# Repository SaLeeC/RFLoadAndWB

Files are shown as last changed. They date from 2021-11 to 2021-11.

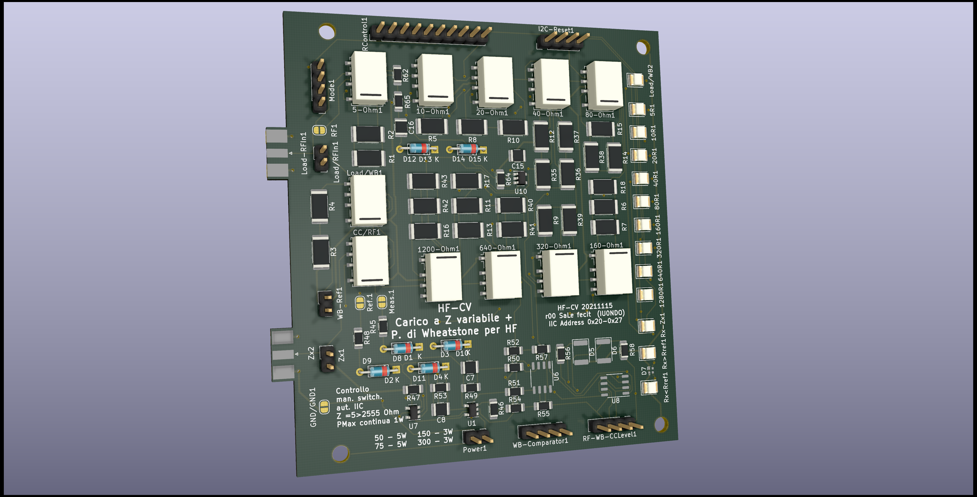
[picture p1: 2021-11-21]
HF_CaricoVariabile/Doc/HF_CaricoVariabile_r00-Front.png

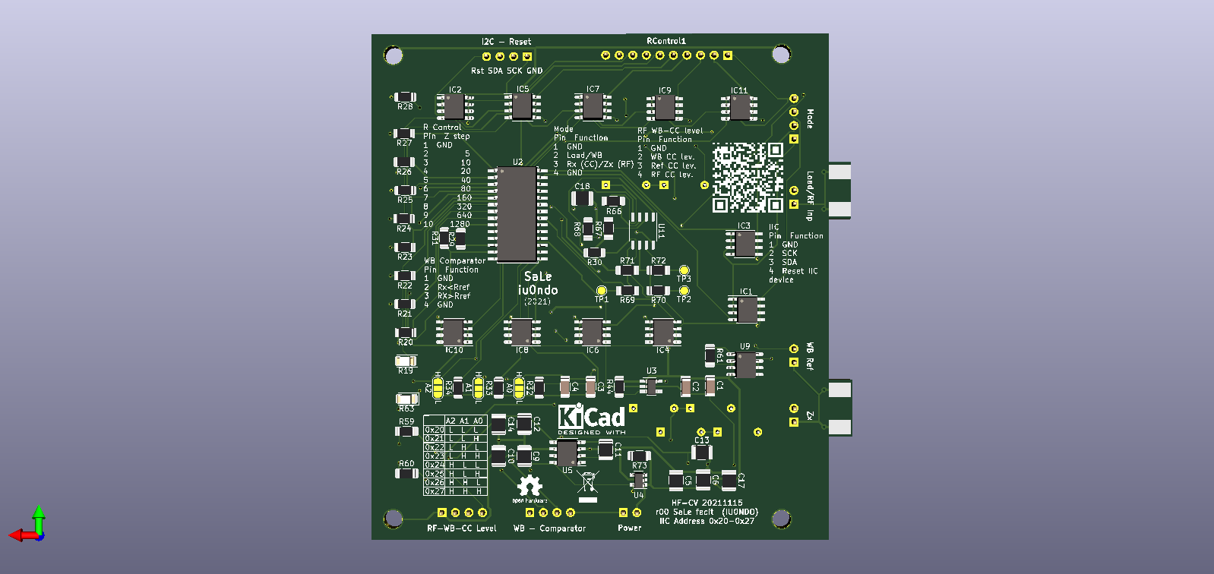
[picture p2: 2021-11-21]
HF_CaricoVariabile/Doc/HF_CaricoVariabile_r00-rear.png

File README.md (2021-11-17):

# RFLoadAndWB
A board to have a low power Variable Z Load and a RF Wheatstone Bridge

The intention is to make a small card (under 10 X 10 cm) that provides a dummy load (low power) with variable impedance between 5 and 2555 Ohm programmable in 5 Ohm steps and, at the same time, a Weathston Bridge which works in direct current and in RF to measure the unknown Z always in the range between 5 and 2555 Ohm.

The project is based on the following finished functional blocks:

a) Variable Z dummy load

b) Reference divider for the Weathston Bridge

c) Constant Current Generator

d) RF-DC converter for the measurement of the incoming Radio Frequency level

e) RF-DC converter for measuring the level of the reference Radio Frequency for the Weathston Bridge

f) RF-DC converter for measuring the level across the Unknown Impedance

g) Comparator for the comparison between the reference and the level at the ends of the Unknown Impedance

h) LED display for the representation of the board status (including the result of the comparison)

i) IIC interface for setting the operating parameters

All modules are finished units so they can be assembled, tested and used separately from each other.

For its operation, the board does not require a microcontroller, PC, software or other devilry, it only requires a series of switches or jumpers with which we can manually set all the operating parameters.

For the measurements a tester or a multimeter is sufficient because all the measured values are converted into Direct Current.

For direct current resistance measurements, the unknown resistor is powered by a 1 mA constant current pump allowing to read its value in Ohm directly in mV.

It is also possible to connect the card to a microcontroller through the interface module in IIC (I2C).

As for the measured values, these are converted into Direct Current and can assume values between 0 and 3.3V allowing easy interfacing with the Analog-Digital converters which are normally equipped with microcontrollers.

The comparator output is digital information and assumes the values of 0 or 3.3V

All the elements that make up the Dummy Load are 1W SMD resistors for which 1W is assumed as the maximum applicable power, in fact, since only the value of 10 Ohm is obtained with a single resistor, if really necessary, it will be possible to apply higher powers in function of the set value. This operation can irreversibly damage the load if during use combinations are chosen that are not able to withstand the applied power. In any case it is recommended not to apply more than 2W.

Inside the board hare present a free Op Amp with minimum circuit usable with Inp+ Inp- and Out for integration and experimental use

All schematics and PCB design are provided in KiCad format

The software is developed with Visual Studio Code through the PlatformIo App and is compatible with the "Arduino" environment

Mechanical drawings are produced with FreeCad.

# RFLoadAndWB
Una scheda che faccia da Carico Fittizio ad Impedenza Variabile e da Ponte di Weathston in RF

l'intenzione è quella di realizzare una piccola scheda (sotto i 10 X 10 cm) che fornisca un carico fittizio (bassa potenza) con impedenza variabile tra 5 e 2555 Ohm programmabile in step di 5 Ohm e, allo stesso tempo, un Weathston Bridge che funzioni in in corrente continua e in RF per misurare lo Z sconosciuto sempre nel range tra 5 e 2555 Ohm.

Il progetto è basato sui seguenti blocchi funzionali finiti:

a) Carico fittizio a Z variabile

b) Partitore di riferimento per il Ponte di Weathston

c) Generatore di Corrente Costante

d) Convertitore RF-DC per la misura del livello della Radio Frequenza in ingresso

e) Convertitore RF-DC per la misura del livello della Radio Frequenza di riferimento per il Ponte di Weathston

f) Convertitore RF-DC per la misura del livello ai capi della Impedenza Incognita

g) Comparatore per il confronto fra il riferimento e il livello ai capi della Impedenza Incognita

h) Display a LED per la rappresentazione dello stato della scheda (compreso il risultato della comparazione)

i) Interfaccia IIC per l'impostazione dei parametri di funzionamento

Tutti i moduli sono unità finite per cui possono essere assemblati, testati e usati separatamente uno dall'altro. 

Per il suo funzionamento la scheda non necessita di microcontrollore, PC, software o altre diavolerie, richiede solo una serie di interruttori o ponticelli con i quali possiamo manualmente impostare tutti i parametri di funzionamento.

Per le misure è sufficiente un tester o un multimetro perchè tutti i valori misurati sono convertiti in Corrente Continua.

Per le misure di resistenza in Corrente Continua la resistenza incognita è alimentata con una pompa di corrente costante da 1 mA permettendo di leggerne il valore in Ohm direttamente in mV.

E' altresì possibile collegare la scheda ad un microcontrollore tramite il modulo di interfacciamento in IIC (I2C).

Per quanto riguarda i valori misurati, questi sono convertiti in Corrente Continua e possono assumere valori compresi fra 0 e 3.3V permettendo un agevole interfacciamento con i convertitori Analogico Digitali di cui normalmente sono dotati i microcontrollori.

L'uscita del comparatore è una informazione digitale ed assume i valori di 0 o 3.3V

Tutti gli elementi che compongono il Carico Fittizio sono resistenze SMD da 1W per cui si assume 1W come potenza massima applicabile, in effetti, siccome solo il valore di 10 Ohm è ottenuto con una sola resistenza, se realmente necessario,sarà possibile applicare potenze maggiori  in funzione del valore impostato. Questa operazione può danneggiare irreversibilmente il carico se durante l'uso si scelgono combinazioni che non siano in grado di sopportare la potenza applicata. In ogni caso si consiglia di non applicare più di 2W.

All'interno della scheda è presente un Op Amp circuitato con i componenti minimi e utilizzabile tramite i pin Inp+ Inp- e Out, da usare per integrazioni o esperimenti.

Tutti gli schemi e il progetto del PCB sono forniti in formato KiCad

Il software è sviluppato con Visual Studio Code tramite l'App PlatformIo ed è compatibile con l'ambiente "Arduino"

I disegni meccanici sono prodotti con FreeCad.

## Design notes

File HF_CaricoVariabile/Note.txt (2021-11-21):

#Comparatrore-Uscita digitale
Dopo aver completato la prima messa a punto del Weatston Bridge e verificato il corretto funzionamento dei singoli blocchi, verificare la corretta sovrapponibilità dell'uscita digitale del comparatore con due bit dell'espander così da poter leggere il comparatore direttamente in I2C.
Questa modifica va fatta aggiungendo due ponticelli cablati

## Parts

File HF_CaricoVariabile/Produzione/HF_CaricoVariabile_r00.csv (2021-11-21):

Reference | Value | Footprint | Datasheet | Arrow Part Number | Arrow Price/Stock | Description | Height | Manufacturer_Name | Manufacturer_Part_Number | Mouser Part Number | Mouser Price/Stock
I2C-Reset1 | Conn_01x04_Female | Connector_PinHeader_2.54mm:PinHeader_1x04_P2.54mm_Vertical | ~
Power1 | Conn_01x02_Female | Connector_PinHeader_2.54mm:PinHeader_1x02_P2.54mm_Vertical | ~
RF-WB-CCLevel1 | Conn_01x04_Female | Connector_PinHeader_2.54mm:PinHeader_1x04_P2.54mm_Vertical | ~
WB-Comparator1 | Conn_01x04_Female | Connector_PinHeader_2.54mm:PinHeader_1x04_P2.54mm_Vertical | ~
Mode1 | Conn_01x04_Female | Connector_PinHeader_2.54mm:PinHeader_1x04_P2.54mm_Vertical | ~
RControl1 | Conn_01x10_Female | Connector_PinHeader_2.54mm:PinHeader_1x10_P2.54mm_Vertical | ~
GND/GND1 | GND/GND | Jumper:SolderJumper-2_P1.3mm_Open_RoundedPad1.0x1.5mm | ~
D16 | SD12 | Diode_SMD:D_1812_4532Metric | https://assets.nexperia.com/documents/data-sheet/1N4148_1N4448.pdf
Rx-Zx2 | LED | LED_SMD:LED_1210_3225Metric | ~
R74 | R | LED_SMD:LED_1206_3216Metric | ~
R2 | 10 | Resistor_SMD:R_2512_6332Metric | ~
5-Ohm1 | 5 Ohm | Relay_SMD:Relay_DPDT_Omron_G6K-2F-Y | http://omronfs.omron.com/en_US/ecb/products/pdf/en-g6k.pdf
Load-RFIn1 | Load/RFin | Connector_Coaxial:SMA_Molex_73251-2120_EdgeMount_Horizontal | ~
10-Ohm1 | 10 Ohm | Relay_SMD:Relay_DPDT_Omron_G6K-2F-Y | http://omronfs.omron.com/en_US/ecb/products/pdf/en-g6k.pdf
R1 | 10 | Resistor_SMD:R_2512_6332Metric | ~
20-Ohm1 | 20 Ohm | Relay_SMD:Relay_DPDT_Omron_G6K-2F-Y | http://omronfs.omron.com/en_US/ecb/products/pdf/en-g6k.pdf
40-Ohm1 | 40 Ohm | Relay_SMD:Relay_DPDT_Omron_G6K-2F-Y | http://omronfs.omron.com/en_US/ecb/products/pdf/en-g6k.pdf
R5 | 10 | Resistor_SMD:R_2512_6332Metric | ~
80-Ohm1 | 80 Ohm | Relay_SMD:Relay_DPDT_Omron_G6K-2F-Y | http://omronfs.omron.com/en_US/ecb/products/pdf/en-g6k.pdf
160-Ohm1 | 160 Ohm | Relay_SMD:Relay_DPDT_Omron_G6K-2F-Y | http://omronfs.omron.com/en_US/ecb/products/pdf/en-g6k.pdf
320-Ohm1 | 320 Ohm | Relay_SMD:Relay_DPDT_Omron_G6K-2F-Y | http://omronfs.omron.com/en_US/ecb/products/pdf/en-g6k.pdf
640-Ohm1 | 640 Ohm | Relay_SMD:Relay_DPDT_Omron_G6K-2F-Y | http://omronfs.omron.com/en_US/ecb/products/pdf/en-g6k.pdf
1200-Ohm1 | 1200 Ohm | Relay_SMD:Relay_DPDT_Omron_G6K-2F-Y | http://omronfs.omron.com/en_US/ecb/products/pdf/en-g6k.pdf
R15 | 120 | Resistor_SMD:R_2512_6332Metric | ~
R14 | 120 | Resistor_SMD:R_2512_6332Metric | ~
R9 | 100 | Resistor_SMD:R_2512_6332Metric | ~
R6 | 330 | Resistor_SMD:R_2512_6332Metric | ~
R11 | 330 | Resistor_SMD:R_2512_6332Metric | ~
R13 | 100 | Resistor_SMD:R_2512_6332Metric | ~
R16 | 4700 | Resistor_SMD:R_2512_6332Metric | ~
R17 | 1000 | Resistor_SMD:R_2512_6332Metric | ~
Load/WB1 | 5 Ohm | Relay_SMD:Relay_DPDT_Omron_G6K-2F-Y | http://omronfs.omron.com/en_US/ecb/products/pdf/en-g6k.pdf
Zx2 | Zx | Connector_Coaxial:SMA_Molex_73251-2120_EdgeMount_Horizontal | ~
R4 | 1000 | Resistor_SMD:R_2512_6332Metric | ~
R3 | 1000 | Resistor_SMD:R_2512_6332Metric | ~
Load/RFIn1 | Load/RFIn | Connector_PinHeader_2.54mm:PinHeader_1x02_P2.54mm_Vertical | ~
WB-Ref1 | RFRef | Connector_PinHeader_2.54mm:PinHeader_1x02_P2.54mm_Vertical | ~
Zx1 | Zx | Connector_PinHeader_2.54mm:PinHeader_1x02_P2.54mm_Vertical | ~
R8 | 10 | Resistor_SMD:R_2512_6332Metric | ~
R10 | 10 | Resistor_SMD:R_2512_6332Metric | ~
R12 | 10 | Resistor_SMD:R_2512_6332Metric | ~
R37 | 10 | Resistor_SMD:R_2512_6332Metric | ~
R35 | 10 | Resistor_SMD:R_2512_6332Metric | ~
R36 | 10 | Resistor_SMD:R_2512_6332Metric | ~
R38 | 120 | Resistor_SMD:R_2512_6332Metric | ~
R7 | 330 | Resistor_SMD:R_2512_6332Metric | ~
R18 | 4700 | Resistor_SMD:R_2512_6332Metric | ~
R39 | 220 | Resistor_SMD:R_2512_6332Metric | ~
R40 | 220 | Resistor_SMD:R_2512_6332Metric | ~
R41 | 4700 | Resistor_SMD:R_2512_6332Metric | ~
R42 | 330 | Resistor_SMD:R_2512_6332Metric | ~
R43 | 4700 | Resistor_SMD:R_2512_6332Metric | ~
U9 | LM334M | Package_SO:SOIC-8_3.9x4.9mm_P1.27mm | http://www.ti.com/lit/ds/symlink/lm134.pdf
R61 | 68 | Resistor_SMD:R_1206_3216Metric_Pad1.30x1.75mm_HandSolder | ~
CC/RF1 | CC-RF | Relay_SMD:Relay_DPDT_Omron_G6K-2F-Y | http://omronfs.omron.com/en_US/ecb/products/pdf/en-g6k.pdf
U7 | OPA356 | Package_TO_SOT_SMD:SOT-23-5 | http://www.ti.com/lit/ds/symlink/opa356.pdf
R53 | 220K | Resistor_SMD:R_1206_3216Metric_Pad1.30x1.75mm_HandSolder | ~
R48 | 100K | Resistor_SMD:R_1206_3216Metric_Pad1.30x1.75mm_HandSolder | ~
U5 | ICL7660 | Package_SO:SOIC-8_3.9x4.9mm_P1.27mm | http://datasheets.maximintegrated.com/en/ds/ICL7660-MAX1044.pdf
U4 | TLV70033_SOT23-5 | Package_TO_SOT_SMD:SOT-23-5 | http://www.ti.com/lit/ds/symlink/tlv700.pdf
R57 | 10k | Resistor_SMD:R_1206_3216Metric_Pad1.30x1.75mm_HandSolder | ~
D4 | 1N4148 | Diode_THT:D_DO-35_SOD27_P7.62mm_Horizontal | https://assets.nexperia.com/documents/data-sheet/1N4148_1N4448.pdf
D2 | 1N4148 | Diode_THT:D_DO-35_SOD27_P7.62mm_Horizontal | https://assets.nexperia.com/documents/data-sheet/1N4148_1N4448.pdf
R55 | 10K | Resistor_SMD:R_1206_3216Metric_Pad1.30x1.75mm_HandSolder | ~
C8 | 100n | Resistor_SMD:R_1210_3225Metric | ~
R47 | 47K | Resistor_SMD:R_1206_3216Metric_Pad1.30x1.75mm_HandSolder | ~
U1 | OPA356 | Package_TO_SOT_SMD:SOT-23-5 | http://www.ti.com/lit/ds/symlink/opa356.pdf
R49 | 220K | Resistor_SMD:R_1206_3216Metric_Pad1.30x1.75mm_HandSolder | ~
R45 | 100K | Resistor_SMD:R_1206_3216Metric_Pad1.30x1.75mm_HandSolder | ~
D3 | 1N4148 | Diode_THT:D_DO-35_SOD27_P7.62mm_Horizontal | https://assets.nexperia.com/documents/data-sheet/1N4148_1N4448.pdf
D1 | 1N4148 | Diode_THT:D_DO-35_SOD27_P7.62mm_Horizontal | https://assets.nexperia.com/documents/data-sheet/1N4148_1N4448.pdf
C7 | 100n | Resistor_SMD:R_1210_3225Metric | ~
R46 | 47K | Resistor_SMD:R_1206_3216Metric_Pad1.30x1.75mm_HandSolder | ~
U6 | TL072 | Package_SO:SOP-8_3.9x4.9mm_P1.27mm | http://www.ti.com/lit/ds/symlink/tl071.pdf
R54 | 10K | Resistor_SMD:R_1206_3216Metric_Pad1.30x1.75mm_HandSolder | ~
R52 | 10K | Resistor_SMD:R_1206_3216Metric_Pad1.30x1.75mm_HandSolder | ~
R50 | 100K | Resistor_SMD:R_1206_3216Metric_Pad1.30x1.75mm_HandSolder | ~
R51 | 100K | Resistor_SMD:R_1206_3216Metric_Pad1.30x1.75mm_HandSolder | ~
Ref.1 | Jumper_2_Open | Jumper:SolderJumper-2_P1.3mm_Open_RoundedPad1.0x1.5mm | ~
Meas.1 | Jumper_2_Open | Jumper:SolderJumper-2_P1.3mm_Open_RoundedPad1.0x1.5mm | ~
C6 | 100n | Resistor_SMD:R_1210_3225Metric | ~
C5 | 100u | Resistor_SMD:R_1210_3225Metric | ~
C9 | 100u | Resistor_SMD:R_1210_3225Metric | ~
C10 | 100n | Resistor_SMD:R_1210_3225Metric | ~
C12 | 100u | Resistor_SMD:R_1210_3225Metric | ~
C14 | 100n | Resistor_SMD:R_1210_3225Metric | ~
C11 | 10u | Resistor_SMD:R_1210_3225Metric | ~
C13 | 10n | Resistor_SMD:R_1210_3225Metric | ~
C15 | 10n | Resistor_SMD:R_1210_3225Metric | ~
U8 | TL072 | Package_SO:SOP-8_3.9x4.9mm_P1.27mm | http://www.ti.com/lit/ds/symlink/tl071.pdf
R60 | 100 | Resistor_SMD:R_1206_3216Metric_Pad1.30x1.75mm_HandSolder | ~
R59 | 100 | Resistor_SMD:R_1206_3216Metric_Pad1.30x1.75mm_HandSolder | ~
D7 | LED_Dual_CACA | LED_SMD:LED_SK6812_EC15_1.5x1.5mm | ~
Rx<Rref1 | LED | LED_SMD:LED_1210_3225Metric | ~
Rx>Rref1 | LED | LED_SMD:LED_1210_3225Metric | ~
R56 | 10K | Resistor_SMD:R_1206_3216Metric_Pad1.30x1.75mm_HandSolder | ~
R58 | 10K | Resistor_SMD:R_1206_3216Metric_Pad1.30x1.75mm_HandSolder | ~
D5 | SD12 | Diode_SMD:D_1812_4532Metric | https://assets.nexperia.com/documents/data-sheet/1N4148_1N4448.pdf
D6 | SD12 | Diode_SMD:D_1812_4532Metric | https://assets.nexperia.com/documents/data-sheet/1N4148_1N4448.pdf
D8 | 1N4148 | Diode_SMD:D_1206_3216Metric | https://assets.nexperia.com/documents/data-sheet/1N4148_1N4448.pdf
D10 | 1N4148 | Diode_SMD:D_1206_3216Metric | https://assets.nexperia.com/documents/data-sheet/1N4148_1N4448.pdf
D11 | 1N4148 | Diode_SMD:D_1206_3216Metric | https://assets.nexperia.com/documents/data-sheet/1N4148_1N4448.pdf
D9 | 1N4148 | Diode_SMD:D_1206_3216Metric | https://assets.nexperia.com/documents/data-sheet/1N4148_1N4448.pdf
R68 | 10k | Resistor_SMD:R_1206_3216Metric_Pad1.30x1.75mm_HandSolder | ~
U10 | OPA356 | Package_TO_SOT_SMD:SOT-23-5 | http://www.ti.com/lit/ds/symlink/opa356.pdf
R65 | 220K | Resistor_SMD:R_1206_3216Metric_Pad1.30x1.75mm_HandSolder | ~
R62 | 100K | Resistor_SMD:R_1206_3216Metric_Pad1.30x1.75mm_HandSolder | ~
D15 | 1N4148 | Diode_THT:D_DO-35_SOD27_P7.62mm_Horizontal | https://assets.nexperia.com/documents/data-sheet/1N4148_1N4448.pdf
D12 | 1N4148 | Diode_THT:D_DO-35_SOD27_P7.62mm_Horizontal | https://assets.nexperia.com/documents/data-sheet/1N4148_1N4448.pdf
C16 | 100n | Resistor_SMD:R_1210_3225Metric | ~
R64 | 47K | Resistor_SMD:R_1206_3216Metric_Pad1.30x1.75mm_HandSolder | ~
R67 | 10K | Resistor_SMD:R_1206_3216Metric_Pad1.30x1.75mm_HandSolder | ~
R66 | 100K | Resistor_SMD:R_1206_3216Metric_Pad1.30x1.75mm_HandSolder | ~
RF1 | Jumper_2_Open | Jumper:SolderJumper-2_P1.3mm_Open_RoundedPad1.0x1.5mm | ~
C17 | 10n | Resistor_SMD:R_1210_3225Metric | ~
C18 | 10n | Resistor_SMD:R_1210_3225Metric | ~
D13 | 1N4148 | Diode_SMD:D_1206_3216Metric | https://assets.nexperia.com/documents/data-sheet/1N4148_1N4448.pdf
D14 | 1N4148 | Diode_SMD:D_1206_3216Metric | https://assets.nexperia.com/documents/data-sheet/1N4148_1N4448.pdf
R73 | 100K | Resistor_SMD:R_1206_3216Metric_Pad1.30x1.75mm_HandSolder | ~
R69 | 100K | Resistor_SMD:R_1206_3216Metric_Pad1.30x1.75mm_HandSolder | ~
R71 | 100K | Resistor_SMD:R_1206_3216Metric_Pad1.30x1.75mm_HandSolder | ~
R72 | 100K | Resistor_SMD:R_1206_3216Metric_Pad1.30x1.75mm_HandSolder | ~
R70 | 100K | Resistor_SMD:R_1206_3216Metric_Pad1.30x1.75mm_HandSolder | ~
Inp+1 | TestPoint | TestPoint:TestPoint_Pad_D1.5mm | ~
Inp-1 | TestPoint | TestPoint:TestPoint_Pad_D1.5mm | ~
Out1 | TestPoint | TestPoint:TestPoint_Pad_D1.5mm | ~
U11 | TL072 | Package_SO:SOP-8_3.9x4.9mm_P1.27mm | http://www.ti.com/lit/ds/symlink/tl071.pdf
IC2 | STS6NF20V | Package_SO:SOIC-8_3.9x4.9mm_P1.27mm | http://www.st.com/st-web-ui/static/active/en/resource/technical/document/datasheet/CD00002342.pdf | STS6NF20V | https://www.arrow.com/en/products/sts6nf20v/stmicroelectronics | STS6NF20V, N-channel MOSFET Transistor 6A 20V, 8-Pin SO | 1.75 | STMicroelectronics | STS6NF20V | 511-STS6NF20V | https://www.mouser.com/Search/Refine.aspx?Keyword=511-STS6NF20V
IC5 | STS6NF20V | Package_SO:SOIC-8_3.9x4.9mm_P1.27mm | http://www.st.com/st-web-ui/static/active/en/resource/technical/document/datasheet/CD00002342.pdf | STS6NF20V | https://www.arrow.com/en/products/sts6nf20v/stmicroelectronics | STS6NF20V, N-channel MOSFET Transistor 6A 20V, 8-Pin SO | 1.75 | STMicroelectronics | STS6NF20V | 511-STS6NF20V | https://www.mouser.com/Search/Refine.aspx?Keyword=511-STS6NF20V
IC6 | STS6NF20V | Package_SO:SOIC-8_3.9x4.9mm_P1.27mm | http://www.st.com/st-web-ui/static/active/en/resource/technical/document/datasheet/CD00002342.pdf | STS6NF20V | https://www.arrow.com/en/products/sts6nf20v/stmicroelectronics | STS6NF20V, N-channel MOSFET Transistor 6A 20V, 8-Pin SO | 1.75 | STMicroelectronics | STS6NF20V | 511-STS6NF20V | https://www.mouser.com/Search/Refine.aspx?Keyword=511-STS6NF20V
IC7 | STS6NF20V | Package_SO:SOIC-8_3.9x4.9mm_P1.27mm | http://www.st.com/st-web-ui/static/active/en/resource/technical/document/datasheet/CD00002342.pdf | STS6NF20V | https://www.arrow.com/en/products/sts6nf20v/stmicroelectronics | STS6NF20V, N-channel MOSFET Transistor 6A 20V, 8-Pin SO | 1.75 | STMicroelectronics | STS6NF20V | 511-STS6NF20V | https://www.mouser.com/Search/Refine.aspx?Keyword=511-STS6NF20V
IC8 | STS6NF20V | Package_SO:SOIC-8_3.9x4.9mm_P1.27mm | http://www.st.com/st-web-ui/static/active/en/resource/technical/document/datasheet/CD00002342.pdf | STS6NF20V | https://www.arrow.com/en/products/sts6nf20v/stmicroelectronics | STS6NF20V, N-channel MOSFET Transistor 6A 20V, 8-Pin SO | 1.75 | STMicroelectronics | STS6NF20V | 511-STS6NF20V | https://www.mouser.com/Search/Refine.aspx?Keyword=511-STS6NF20V
IC9 | STS6NF20V | Package_SO:SOIC-8_3.9x4.9mm_P1.27mm | http://www.st.com/st-web-ui/static/active/en/resource/technical/document/datasheet/CD00002342.pdf | STS6NF20V | https://www.arrow.com/en/products/sts6nf20v/stmicroelectronics | STS6NF20V, N-channel MOSFET Transistor 6A 20V, 8-Pin SO | 1.75 | STMicroelectronics | STS6NF20V | 511-STS6NF20V | https://www.mouser.com/Search/Refine.aspx?Keyword=511-STS6NF20V
IC10 | STS6NF20V | Package_SO:SOIC-8_3.9x4.9mm_P1.27mm | http://www.st.com/st-web-ui/static/active/en/resource/technical/document/datasheet/CD00002342.pdf | STS6NF20V | https://www.arrow.com/en/products/sts6nf20v/stmicroelectronics | STS6NF20V, N-channel MOSFET Transistor 6A 20V, 8-Pin SO | 1.75 | STMicroelectronics | STS6NF20V | 511-STS6NF20V | https://www.mouser.com/Search/Refine.aspx?Keyword=511-STS6NF20V
IC11 | STS6NF20V | Package_SO:SOIC-8_3.9x4.9mm_P1.27mm | http://www.st.com/st-web-ui/static/active/en/resource/technical/document/datasheet/CD00002342.pdf | STS6NF20V | https://www.arrow.com/en/products/sts6nf20v/stmicroelectronics | STS6NF20V, N-channel MOSFET Transistor 6A 20V, 8-Pin SO | 1.75 | STMicroelectronics | STS6NF20V | 511-STS6NF20V | https://www.mouser.com/Search/Refine.aspx?Keyword=511-STS6NF20V
1280R1 | LED | LED_SMD:LED_1210_3225Metric | ~
R19 | R | LED_SMD:LED_1206_3216Metric | ~
640R1 | LED | LED_SMD:LED_1210_3225Metric | ~
R20 | R | Resistor_SMD:R_1206_3216Metric | ~
320R1 | LED | LED_SMD:LED_1210_3225Metric | ~
R21 | R | Resistor_SMD:R_1206_3216Metric | ~
160R1 | LED | LED_SMD:LED_1210_3225Metric | ~
R22 | R | Resistor_SMD:R_1206_3216Metric | ~
80R1 | LED | LED_SMD:LED_1210_3225Metric | ~
R23 | R | Resistor_SMD:R_1206_3216Metric | ~
40R1 | LED | LED_SMD:LED_1210_3225Metric | ~
R24 | R | Resistor_SMD:R_1206_3216Metric | ~
20R1 | LED | LED_SMD:LED_1210_3225Metric | ~
R25 | R | Resistor_SMD:R_1206_3216Metric | ~
10R1 | LED | LED_SMD:LED_1210_3225Metric | ~
R26 | R | Resistor_SMD:R_1206_3216Metric | ~
5R1 | LED | LED_SMD:LED_1210_3225Metric | ~
R27 | R | Resistor_SMD:R_1206_3216Metric | ~
Load/WB2 | LED | LED_SMD:LED_1210_3225Metric | ~
R28 | R | Resistor_SMD:R_1206_3216Metric | ~
IC3 | STS6NF20V | Package_SO:SOIC-8_3.9x4.9mm_P1.27mm | http://www.st.com/st-web-ui/static/active/en/resource/technical/document/datasheet/CD00002342.pdf | STS6NF20V | https://www.arrow.com/en/products/sts6nf20v/stmicroelectronics | STS6NF20V, N-channel MOSFET Transistor 6A 20V, 8-Pin SO | 1.75 | STMicroelectronics | STS6NF20V | 511-STS6NF20V | https://www.mouser.com/Search/Refine.aspx?Keyword=511-STS6NF20V
A0 | Jumper_3_Open | Jumper:SolderJumper-3_P1.3mm_Open_RoundedPad1.0x1.5mm_NumberLabels | ~
A1 | Jumper_3_Open | Jumper:SolderJumper-3_P1.3mm_Open_RoundedPad1.0x1.5mm_NumberLabels | ~
A2 | Jumper_3_Open | Jumper:SolderJumper-3_P1.3mm_Open_RoundedPad1.0x1.5mm_NumberLabels | ~
U2 | MCP23017_SO | Package_SO:SOIC-28W_7.5x17.9mm_P1.27mm | http://ww1.microchip.com/downloads/en/DeviceDoc/20001952C.pdf
R30 | R | Resistor_SMD:R_1206_3216Metric | ~
R29 | R | Resistor_SMD:R_1206_3216Metric | ~
R31 | R | Resistor_SMD:R_1206_3216Metric | ~
R33 | R | Resistor_SMD:R_1206_3216Metric | ~
R34 | R | Resistor_SMD:R_1206_3216Metric | ~
R32 | R | Resistor_SMD:R_1206_3216Metric | ~
U3 | TLV70033_SOT23-5 | Package_TO_SOT_SMD:SOT-23-5_HandSoldering | http://www.ti.com/lit/ds/symlink/tlv700.pdf
C1 | C | Capacitor_SMD:C_1206_3216Metric | ~
C2 | C | Capacitor_SMD:C_1206_3216Metric | ~
C3 | C | Capacitor_SMD:C_1206_3216Metric | ~
C4 | C | Capacitor_SMD:C_1206_3216Metric | ~
R44 | R | Resistor_SMD:R_1206_3216Metric | ~
IC1 | STS6NF20V | Package_SO:SOIC-8_3.9x4.9mm_P1.27mm | http://www.st.com/st-web-ui/static/active/en/resource/technical/document/datasheet/CD00002342.pdf | STS6NF20V | https://www.arrow.com/en/products/sts6nf20v/stmicroelectronics | STS6NF20V, N-channel MOSFET Transistor 6A 20V, 8-Pin SO | 1.75 | STMicroelectronics | STS6NF20V | 511-STS6NF20V | https://www.mouser.com/Search/Refine.aspx?Keyword=511-STS6NF20V
IC4 | STS6NF20V | Package_SO:SOIC-8_3.9x4.9mm_P1.27mm | http://www.st.com/st-web-ui/static/active/en/resource/technical/document/datasheet/CD00002342.pdf | STS6NF20V | https://www.arrow.com/en/products/sts6nf20v/stmicroelectronics | STS6NF20V, N-channel MOSFET Transistor 6A 20V, 8-Pin SO | 1.75 | STMicroelectronics | STS6NF20V | 511-STS6NF20V | https://www.mouser.com/Search/Refine.aspx?Keyword=511-STS6NF20V
Rx-Zx1 | LED | LED_SMD:LED_1210_3225Metric | ~
R63 | R | LED_SMD:LED_1206_3216Metric | ~

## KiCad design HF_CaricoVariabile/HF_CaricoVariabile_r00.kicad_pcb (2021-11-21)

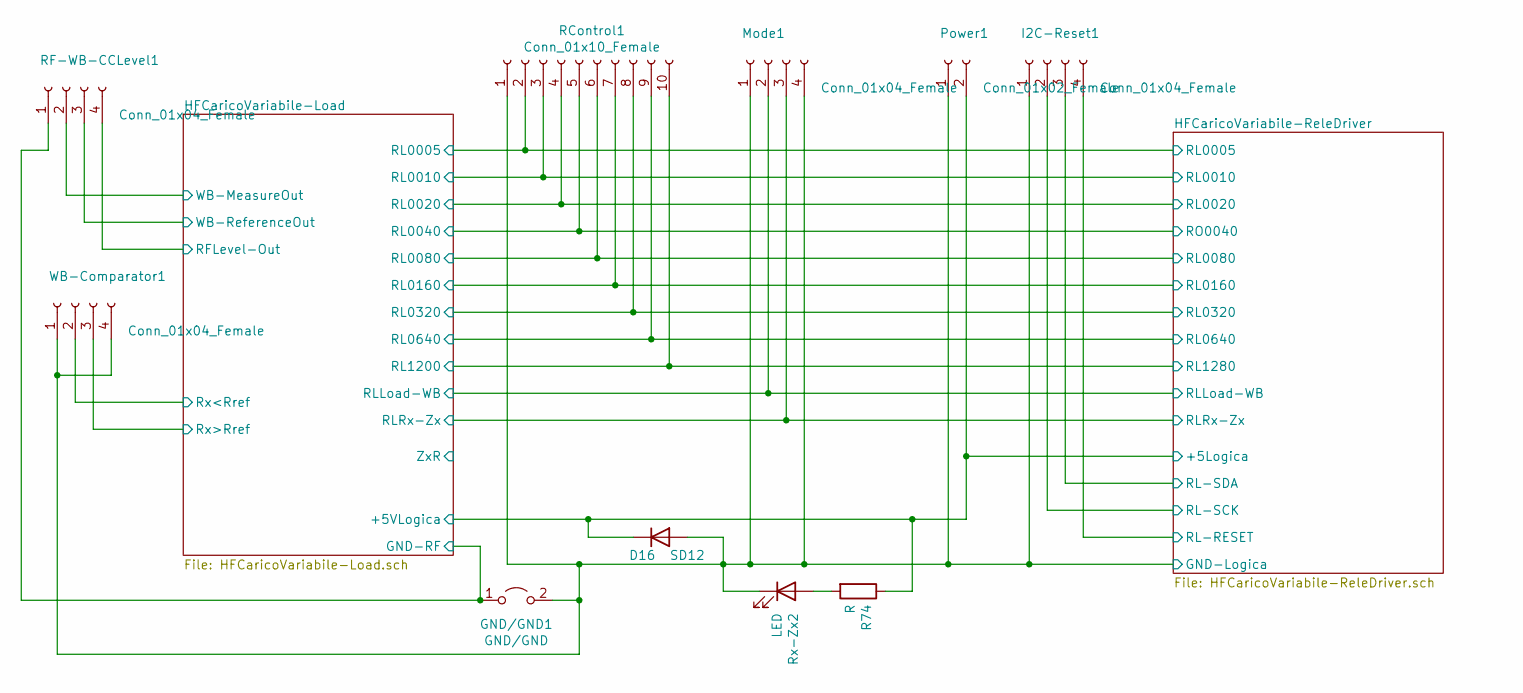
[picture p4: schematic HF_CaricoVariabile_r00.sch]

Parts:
D16: SD12; D_1812_4532Metric
GND/GND1: GND/GND; SolderJumper-2_P1.3mm_Open_RoundedPad1.0x1.5mm
I2C-Reset1: Conn_01x04_Female; PinHeader_1x04_P2.54mm_Vertical
Mode1: Conn_01x04_Female; PinHeader_1x04_P2.54mm_Vertical
Power1: Conn_01x02_Female; PinHeader_1x02_P2.54mm_Vertical
R74: R; LED_1206_3216Metric
RControl1: Conn_01x10_Female; PinHeader_1x10_P2.54mm_Vertical
RF-WB-CCLevel1: Conn_01x04_Female; PinHeader_1x04_P2.54mm_Vertical
Rx-Zx2: LED; LED_1210_3225Metric
WB-Comparator1: Conn_01x04_Female; PinHeader_1x04_P2.54mm_Vertical

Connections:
+5V: D16.1 (K), Power1.2, R74.1; also elsewhere on the board
/HFCaricoVariabile-Load/RFLevel-Out: RF-WB-CCLevel1.4; also elsewhere on the board
/HFCaricoVariabile-Load/RL0005: RControl1.2; also elsewhere on the board
/HFCaricoVariabile-Load/RL0010: RControl1.3; also elsewhere on the board
/HFCaricoVariabile-Load/RL0020: RControl1.4; also elsewhere on the board
/HFCaricoVariabile-Load/RL0040: RControl1.5; also elsewhere on the board
/HFCaricoVariabile-Load/RL0080: RControl1.6; also elsewhere on the board
/HFCaricoVariabile-Load/RL0160: RControl1.7; also elsewhere on the board
/HFCaricoVariabile-Load/RL0320: RControl1.8; also elsewhere on the board
/HFCaricoVariabile-Load/RL0640: RControl1.9; also elsewhere on the board
/HFCaricoVariabile-Load/RL1200: RControl1.10; also elsewhere on the board
/HFCaricoVariabile-Load/RLLoad-WB: Mode1.2; also elsewhere on the board
/HFCaricoVariabile-Load/RLRx-Zx: Mode1.3; also elsewhere on the board
/HFCaricoVariabile-Load/Rx<Rref: WB-Comparator1.2; also elsewhere on the board
/HFCaricoVariabile-Load/Rx>Rref: WB-Comparator1.3; also elsewhere on the board
/HFCaricoVariabile-Load/WB-MeasureOut: RF-WB-CCLevel1.2; also elsewhere on the board
/HFCaricoVariabile-Load/WB-ReferenceOut: RF-WB-CCLevel1.3; also elsewhere on the board
/HFCaricoVariabile-ReleDriver/RL-RESET: I2C-Reset1.4; also elsewhere on the board
/HFCaricoVariabile-ReleDriver/RL-SCK: I2C-Reset1.2; also elsewhere on the board
/HFCaricoVariabile-ReleDriver/RL-SDA: I2C-Reset1.3; also elsewhere on the board
GND: D16.2 (A), GND/GND1.2 (B), I2C-Reset1.1, Mode1.1, Mode1.4, Power1.1, RControl1.1, Rx-Zx2.1 (K), WB-Comparator1.1, WB-Comparator1.4; also elsewhere on the board
GNDA: GND/GND1.1 (A), RF-WB-CCLevel1.1; also elsewhere on the board
unnamed: R74.2, Rx-Zx2.2 (A)

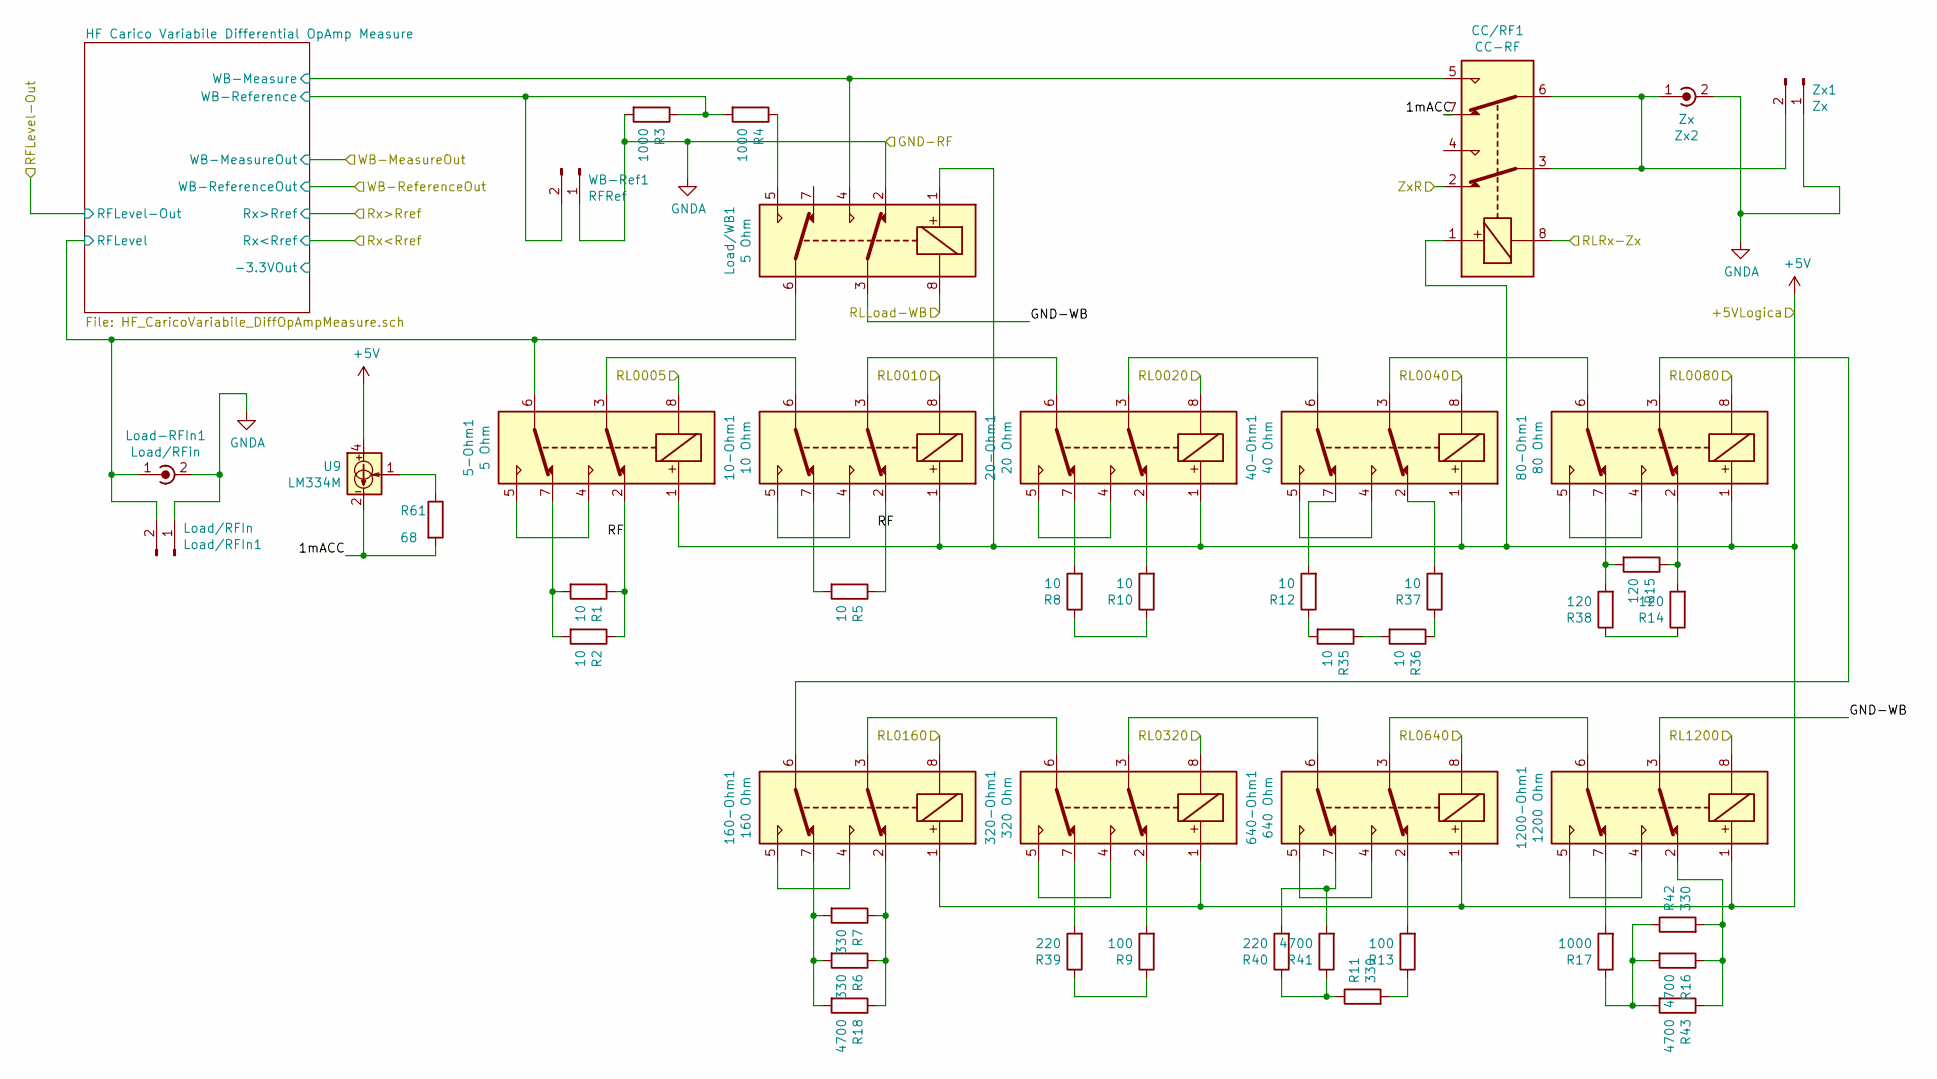
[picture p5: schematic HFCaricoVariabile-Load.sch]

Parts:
5-Ohm1: 5 Ohm; Relay_DPDT_Omron_G6K-2F-Y
10-Ohm1: 10 Ohm; Relay_DPDT_Omron_G6K-2F-Y
20-Ohm1: 20 Ohm; Relay_DPDT_Omron_G6K-2F-Y
40-Ohm1: 40 Ohm; Relay_DPDT_Omron_G6K-2F-Y
80-Ohm1: 80 Ohm; Relay_DPDT_Omron_G6K-2F-Y
160-Ohm1: 160 Ohm; Relay_DPDT_Omron_G6K-2F-Y
320-Ohm1: 320 Ohm; Relay_DPDT_Omron_G6K-2F-Y
640-Ohm1: 640 Ohm; Relay_DPDT_Omron_G6K-2F-Y
1200-Ohm1: 1200 Ohm; Relay_DPDT_Omron_G6K-2F-Y
CC/RF1: CC-RF; Relay_DPDT_Omron_G6K-2F-Y
Load-RFIn1: Load/RFin; SMA_Molex_73251-2120_EdgeMount_Horizontal
Load/RFIn1: Load/RFIn; PinHeader_1x02_P2.54mm_Vertical
Load/WB1: 5 Ohm; Relay_DPDT_Omron_G6K-2F-Y
R1, R2, R5, R8, R10, R12, R35, R36, R37: 10; R_2512_6332Metric
R3, R4, R17: 1000; R_2512_6332Metric
R6, R7, R11, R42: 330; R_2512_6332Metric
R9, R13: 100; R_2512_6332Metric
R14, R15, R38: 120; R_2512_6332Metric
R16, R18, R41, R43: 4700; R_2512_6332Metric
R39, R40: 220; R_2512_6332Metric
R61: 68; R_1206_3216Metric_Pad1.30x1.75mm_HandSolder
U9: LM334M; SOIC-8_3.9x4.9mm_P1.27mm
WB-Ref1: RFRef; PinHeader_1x02_P2.54mm_Vertical
Zx1: Zx; PinHeader_1x02_P2.54mm_Vertical
Zx2: Zx; SMA_Molex_73251-2120_EdgeMount_Horizontal

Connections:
+5V: 5-Ohm1.1, 10-Ohm1.1, 20-Ohm1.1, 40-Ohm1.1, 80-Ohm1.1, 160-Ohm1.1, 320-Ohm1.1, 640-Ohm1.1, 1200-Ohm1.1, CC/RF1.1, Load/WB1.1, U9.4; also elsewhere on the board
/HFCaricoVariabile-Load/1mACC: CC/RF1.7, R61.2, U9.2, U9.3, U9.6, U9.7
/HFCaricoVariabile-Load/GND-WB: 1200-Ohm1.3, Load/WB1.3
/HFCaricoVariabile-Load/HF Carico Variabile Differential OpAmp Measure/RFLevel: 5-Ohm1.6, Load-RFIn1.1 (In), Load/RFIn1.2, Load/WB1.6; also elsewhere on the board
/HFCaricoVariabile-Load/HF Carico Variabile Differential OpAmp Measure/WB-Measu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: CC/RF1.5, Load/WB1.4; also elsewhere on the board
/HFCaricoVariabile-Load/HF Carico Variabile Differential OpAmp Measure/WB-Refer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: R3.1, R4.2, WB-Ref1.2; also elsewhere on the board
/HFCaricoVariabile-Load/RL0005: 5-Ohm1.8; also elsewhere on the board
/HFCaricoVariabile-Load/RL0010: 10-Ohm1.8; also elsewhere on the board
/HFCaricoVariabile-Load/RL0020: 20-Ohm1.8; also elsewhere on the board
/HFCaricoVariabile-Load/RL0040: 40-Ohm1.8; also elsewhere on the board
/HFCaricoVariabile-Load/RL0080: 80-Ohm1.8; also elsewhere on the board
/HFCaricoVariabile-Load/RL0160: 160-Ohm1.8; also elsewhere on the board
/HFCaricoVariabile-Load/RL0320: 320-Ohm1.8; also elsewhere on the board
/HFCaricoVariabile-Load/RL0640: 640-Ohm1.8; also elsewhere on the board
/HFCaricoVariabile-Load/RL1200: 1200-Ohm1.8; also elsewhere on the board
/HFCaricoVariabile-Load/RLLoad-WB: Load/WB1.8; also elsewhere on the board
/HFCaricoVariabile-Load/RLRx-Zx: CC/RF1.8; also elsewhere on the board
/HFCaricoVariabile-Load/ZxR: CC/RF1.2
GNDA: Load-RFIn1.2 (Ext), Load/RFIn1.1, Load/WB1.2, R3.2, WB-Ref1.1, Zx1.1, Zx2.2 (Ext); also elsewhere on the board
unnamed: 5-Ohm1.2, R1.1, R2.1
unnamed: 5-Ohm1.4, 5-Ohm1.5
unnamed: 5-Ohm1.7, R1.2, R2.2
unnamed: 10-Ohm1.2, R5.1
unnamed: 10-Ohm1.3, 20-Ohm1.6
unnamed: 10-Ohm1.4, 10-Ohm1.5
unnamed: 5-Ohm1.3, 10-Ohm1.6
unnamed: 10-Ohm1.7, R5.2
unnamed: 20-Ohm1.2, R10.2
unnamed: 20-Ohm1.3, 40-Ohm1.6
unnamed: 20-Ohm1.4, 20-Ohm1.5
unnamed: 20-Ohm1.7, R8.2
unnamed: 40-Ohm1.2, R37.2
unnamed: 40-Ohm1.3, 80-Ohm1.6
unnamed: 40-Ohm1.4, 40-Ohm1.5
unnamed: 40-Ohm1.7, R12.2
unnamed: 80-Ohm1.2, R14.2, R15.1
unnamed: 80-Ohm1.4, 80-Ohm1.5
unnamed: 80-Ohm1.7, R15.2, R38.2
unnamed: 160-Ohm1.2, R6.1, R7.1, R18.1
unnamed: 160-Ohm1.3, 320-Ohm1.6
unnamed: 160-Ohm1.4, 160-Ohm1.5
unnamed: 80-Ohm1.3, 160-Ohm1.6
unnamed: 160-Ohm1.7, R6.2, R7.2, R18.2
unnamed: 320-Ohm1.2, R9.2
unnamed: 320-Ohm1.3, 640-Ohm1.6
unnamed: 320-Ohm1.4, 320-Ohm1.5
unnamed: 320-Ohm1.7, R39.2
unnamed: 640-Ohm1.2, R13.2
unnamed: 640-Ohm1.4, 640-Ohm1.5
unnamed: 640-Ohm1.7, R40.2, R41.2
unnamed: 1200-Ohm1.2, R16.1, R42.2, R43.1
unnamed: 1200-Ohm1.4, 1200-Ohm1.5
unnamed: 640-Ohm1.3, 1200-Ohm1.6
unnamed: 1200-Ohm1.7, R17.2
unnamed: CC/RF1.3, CC/RF1.6, Zx1.2, Zx2.1 (In)
unnamed: Load/WB1.5, R4.1
unnamed: R8.1, R10.1
unnamed: R11.1, R40.1, R41.1
unnamed: R11.2, R13.1
unnamed: R12.1, R35.2
unnamed: R14.1, R38.1
unnamed: R16.2, R17.1, R42.1, R43.2
unnamed: R35.1, R36.2
unnamed: R36.1, R37.1
unnamed: R9.1, R39.1
unnamed: R61.1, U9.1

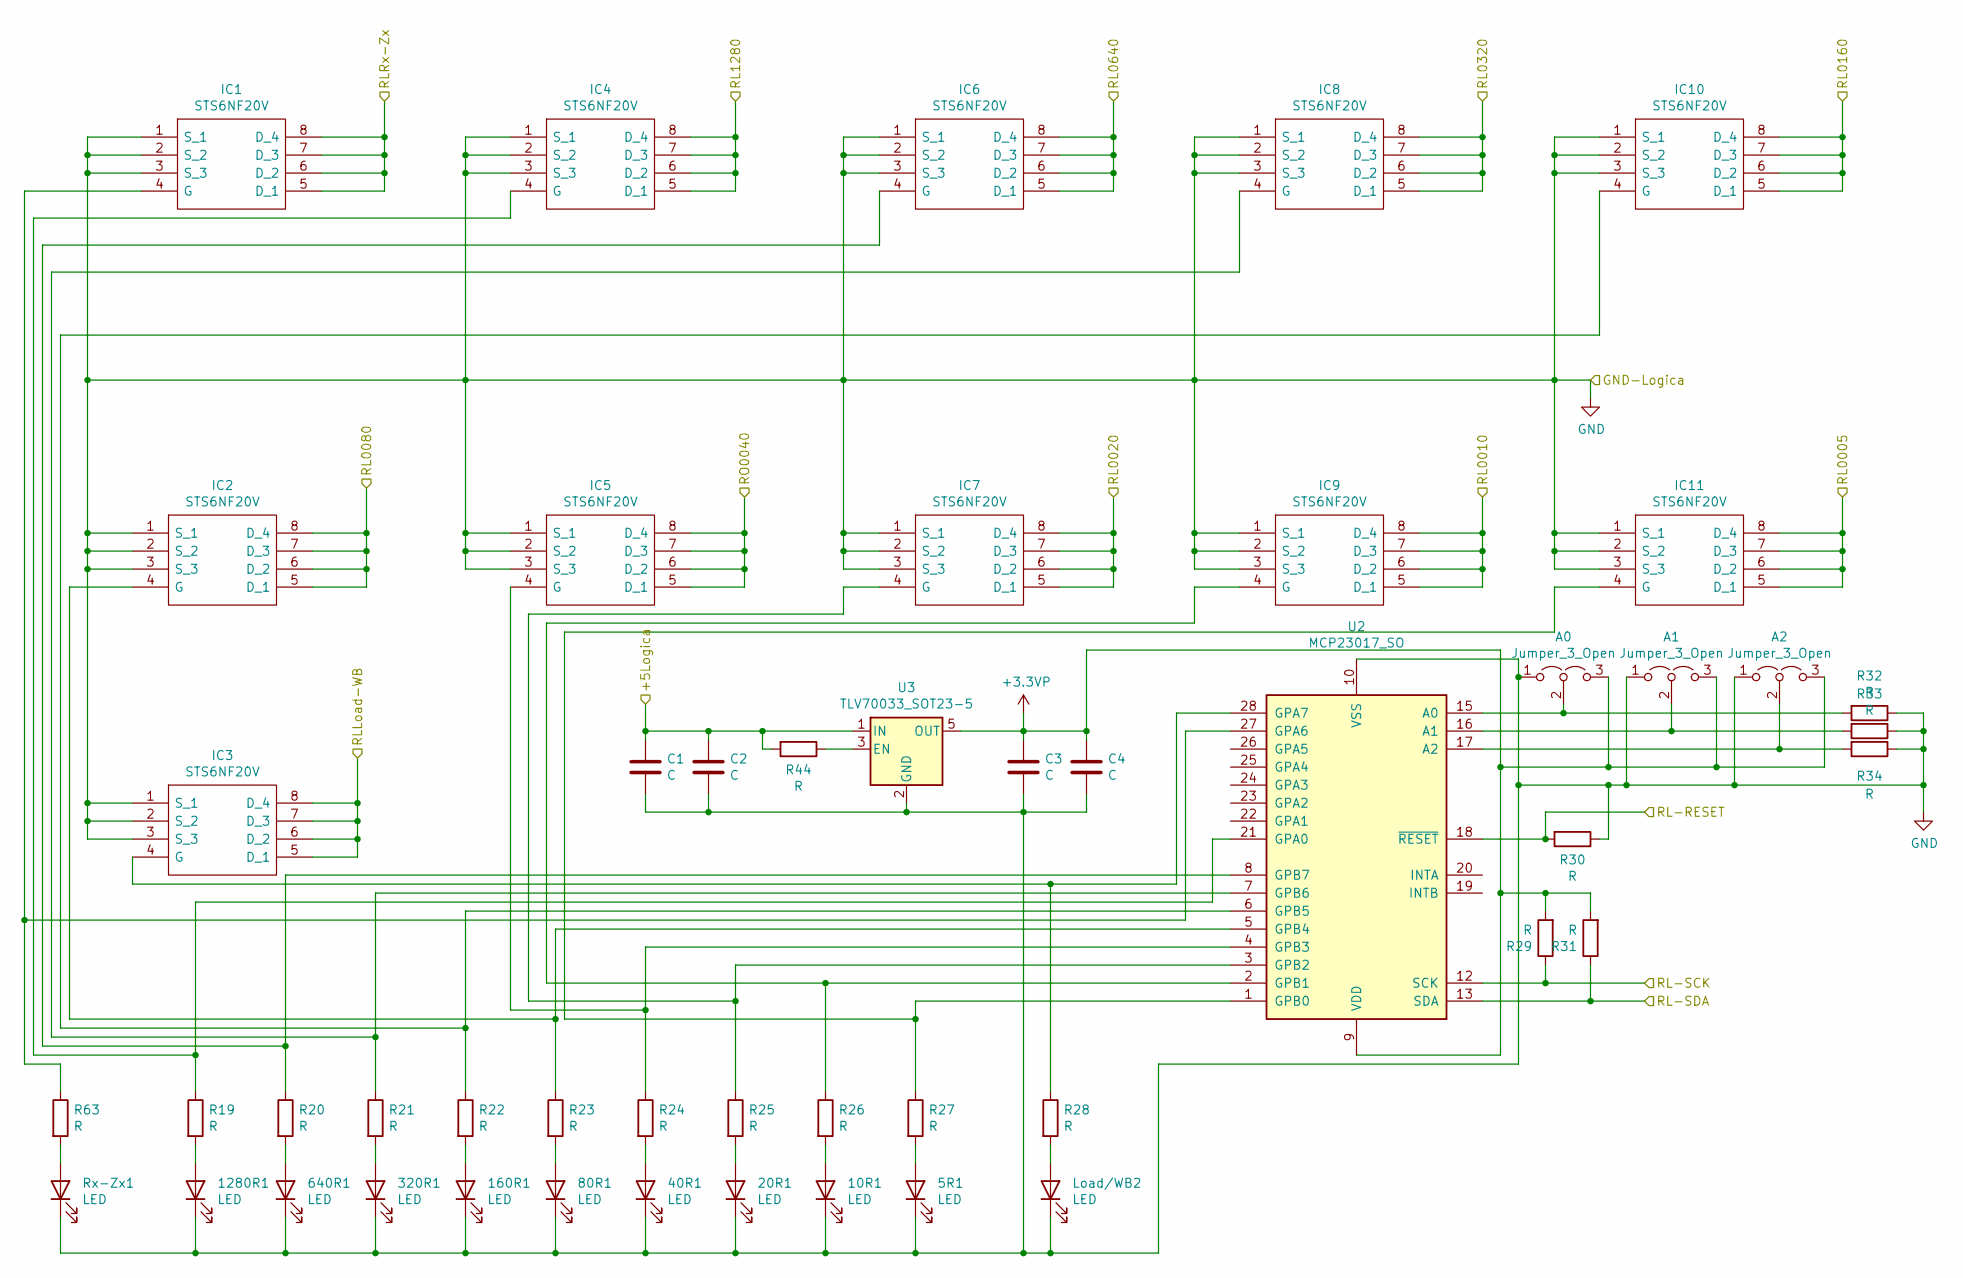
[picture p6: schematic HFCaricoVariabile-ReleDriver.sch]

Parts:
5R1, 10R1, 20R1, 40R1, 80R1, 160R1, 320R1, 640R1, 1280R1: LED; LED_1210_3225Metric
A0, A1, A2: Jumper_3_Open; SolderJumper-3_P1.3mm_Open_RoundedPad1.0x1.5mm_NumberLabels
C1, C2, C3, C4: C; C_1206_3216Metric
IC1, IC2, IC3, IC4, IC5, IC6, IC7, IC8, IC9, IC10, IC11: STS6NF20V; SOIC-8_3.9x4.9mm_P1.27mm; Manufacturer_Part_Number STS6NF20V; Mouser Part Number 511-STS6NF20V
Load/WB2: LED; LED_1210_3225Metric
R19, R63: R; LED_1206_3216Metric
R20, R21, R22, R23, R24, R25, R26, R27, R28, R29, R30, R31, R32, R33, R34, R44: R; R_1206_3216Metric
Rx-Zx1: LED; LED_1210_3225Metric
U2: MCP23017_SO; SOIC-28W_7.5x17.9mm_P1.27mm
U3: TLV70033_SOT23-5; SOT-23-5_HandSoldering

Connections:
+3.3VP: A0.3 (B), A1.3 (B), A2.3 (B), C3.1, C4.1, R29.2, R31.2, U2.9 (VDD), U3.5 (OUT)
+5V: C1.1, C2.1, R44.2, U3.1 (IN); also elsewhere on the board
/HFCaricoVariabile-Load/RL0005: IC11.5 (D_1), IC11.6 (D_2), IC11.7 (D_3), IC11.8 (D_4); also elsewhere on the board
/HFCaricoVariabile-Load/RL0010: IC9.5 (D_1), IC9.6 (D_2), IC9.7 (D_3), IC9.8 (D_4); also elsewhere on the board
/HFCaricoVariabile-Load/RL0020: IC7.5 (D_1), IC7.6 (D_2), IC7.7 (D_3), IC7.8 (D_4); also elsewhere on the board
/HFCaricoVariabile-Load/RL0040: IC5.5 (D_1), IC5.6 (D_2), IC5.7 (D_3), IC5.8 (D_4); also elsewhere on the board
/HFCaricoVariabile-Load/RL0080: IC2.5 (D_1), IC2.6 (D_2), IC2.7 (D_3), IC2.8 (D_4); also elsewhere on the board
/HFCaricoVariabile-Load/RL0160: IC10.5 (D_1), IC10.6 (D_2), IC10.7 (D_3), IC10.8 (D_4); also elsewhere on the board
/HFCaricoVariabile-Load/RL0320: IC8.5 (D_1), IC8.6 (D_2), IC8.7 (D_3), IC8.8 (D_4); also elsewhere on the board
/HFCaricoVariabile-Load/RL0640: IC6.5 (D_1), IC6.6 (D_2), IC6.7 (D_3), IC6.8 (D_4); also elsewhere on the board
/HFCaricoVariabile-Load/RL1200: IC4.5 (D_1), IC4.6 (D_2), IC4.7 (D_3), IC4.8 (D_4); also elsewhere on the board
/HFCaricoVariabile-Load/RLLoad-WB: IC3.5 (D_1), IC3.6 (D_2), IC3.7 (D_3), IC3.8 (D_4); also elsewhere on the board
/HFCaricoVariabile-Load/RLRx-Zx: IC1.5 (D_1), IC1.6 (D_2), IC1.7 (D_3), IC1.8 (D_4); also elsewhere on the board
/HFCaricoVariabile-ReleDriver/RL-RESET: R30.2, U2.18 (~RESET~); also elsewhere on the board
/HFCaricoVariabile-ReleDriver/RL-SCK: R29.1, U2.12 (SCK); also elsewhere on the board
/HFCaricoVariabile-ReleDriver/RL-SDA: R31.1, U2.13 (SDA); also elsewhere on the board
GND: 5R1.1 (K), 10R1.1 (K), 20R1.1 (K), 40R1.1 (K), 80R1.1 (K), 160R1.1 (K), 320R1.1 (K), 640R1.1 (K), 1280R1.1 (K), A0.1 (A), A1.1 (A), A2.1 (A), C1.2, C2.2, C3.2, C4.2, IC1.1 (S_1), IC1.2 (S_2), IC1.3 (S_3), IC2.1 (S_1), IC2.2 (S_2), IC2.3 (S_3), IC3.1 (S_1), IC3.2 (S_2), IC3.3 (S_3), IC4.1 (S_1), IC4.2 (S_2), IC4.3 (S_3), IC5.1 (S_1), IC5.2 (S_2), IC5.3 (S_3), IC6.1 (S_1), IC6.2 (S_2), IC6.3 (S_3), IC7.1 (S_1), IC7.2 (S_2), IC7.3 (S_3), IC8.1 (S_1), IC8.2 (S_2), IC8.3 (S_3), IC9.1 (S_1), IC9.2 (S_2), IC9.3 (S_3), IC10.1 (S_1), IC10.2 (S_2), IC10.3 (S_3), IC11.1 (S_1), IC11.2 (S_2), IC11.3 (S_3), Load/WB2.1 (K), R30.1, R32.1, R33.1, R34.1, Rx-Zx1.1 (K), U2.10 (VSS), U3.2 (GND); also elsewhere on the board
unnamed: 5R1.2 (A), R27.2
unnamed: 10R1.2 (A), R26.2
unnamed: 20R1.2 (A), R25.2
unnamed: 40R1.2 (A), R24.2
unnamed: 80R1.2 (A), R23.2
unnamed: 160R1.2 (A), R22.2
unnamed: 320R1.2 (A), R21.2
unnamed: 640R1.2 (A), R20.2
unnamed: 1280R1.2 (A), R19.2
unnamed: A0.2 (C), R32.2, U2.15 (A0)
unnamed: A1.2 (C), R33.2, U2.16 (A1)
unnamed: A2.2 (C), R34.2, U2.17 (A2)
unnamed: IC1.4 (G), R63.1, U2.27 (GPA6)
unnamed: IC2.4 (G), R23.1, U2.5 (GPB4)
unnamed: IC3.4 (G), R28.1, U2.28 (GPA7)
unnamed: IC4.4 (G), R19.1, U2.21 (GPA0)
unnamed: IC5.4 (G), R24.1, U2.4 (GPB3)
unnamed: IC6.4 (G), R20.1, U2.8 (GPB7)
unnamed: IC7.4 (G), R25.1, U2.3 (GPB2)
unnamed: IC8.4 (G), R21.1, U2.7 (GPB6)
unnamed: IC9.4 (G), R26.1, U2.2 (GPB1)
unnamed: IC10.4 (G), R22.1, U2.6 (GPB5)
unnamed: IC11.4 (G), R27.1, U2.1 (GPB0)
unnamed: Load/WB2.2 (A), R28.2
unnamed: R44.1, U3.3 (EN)
unnamed: R63.2, Rx-Zx1.2 (A)

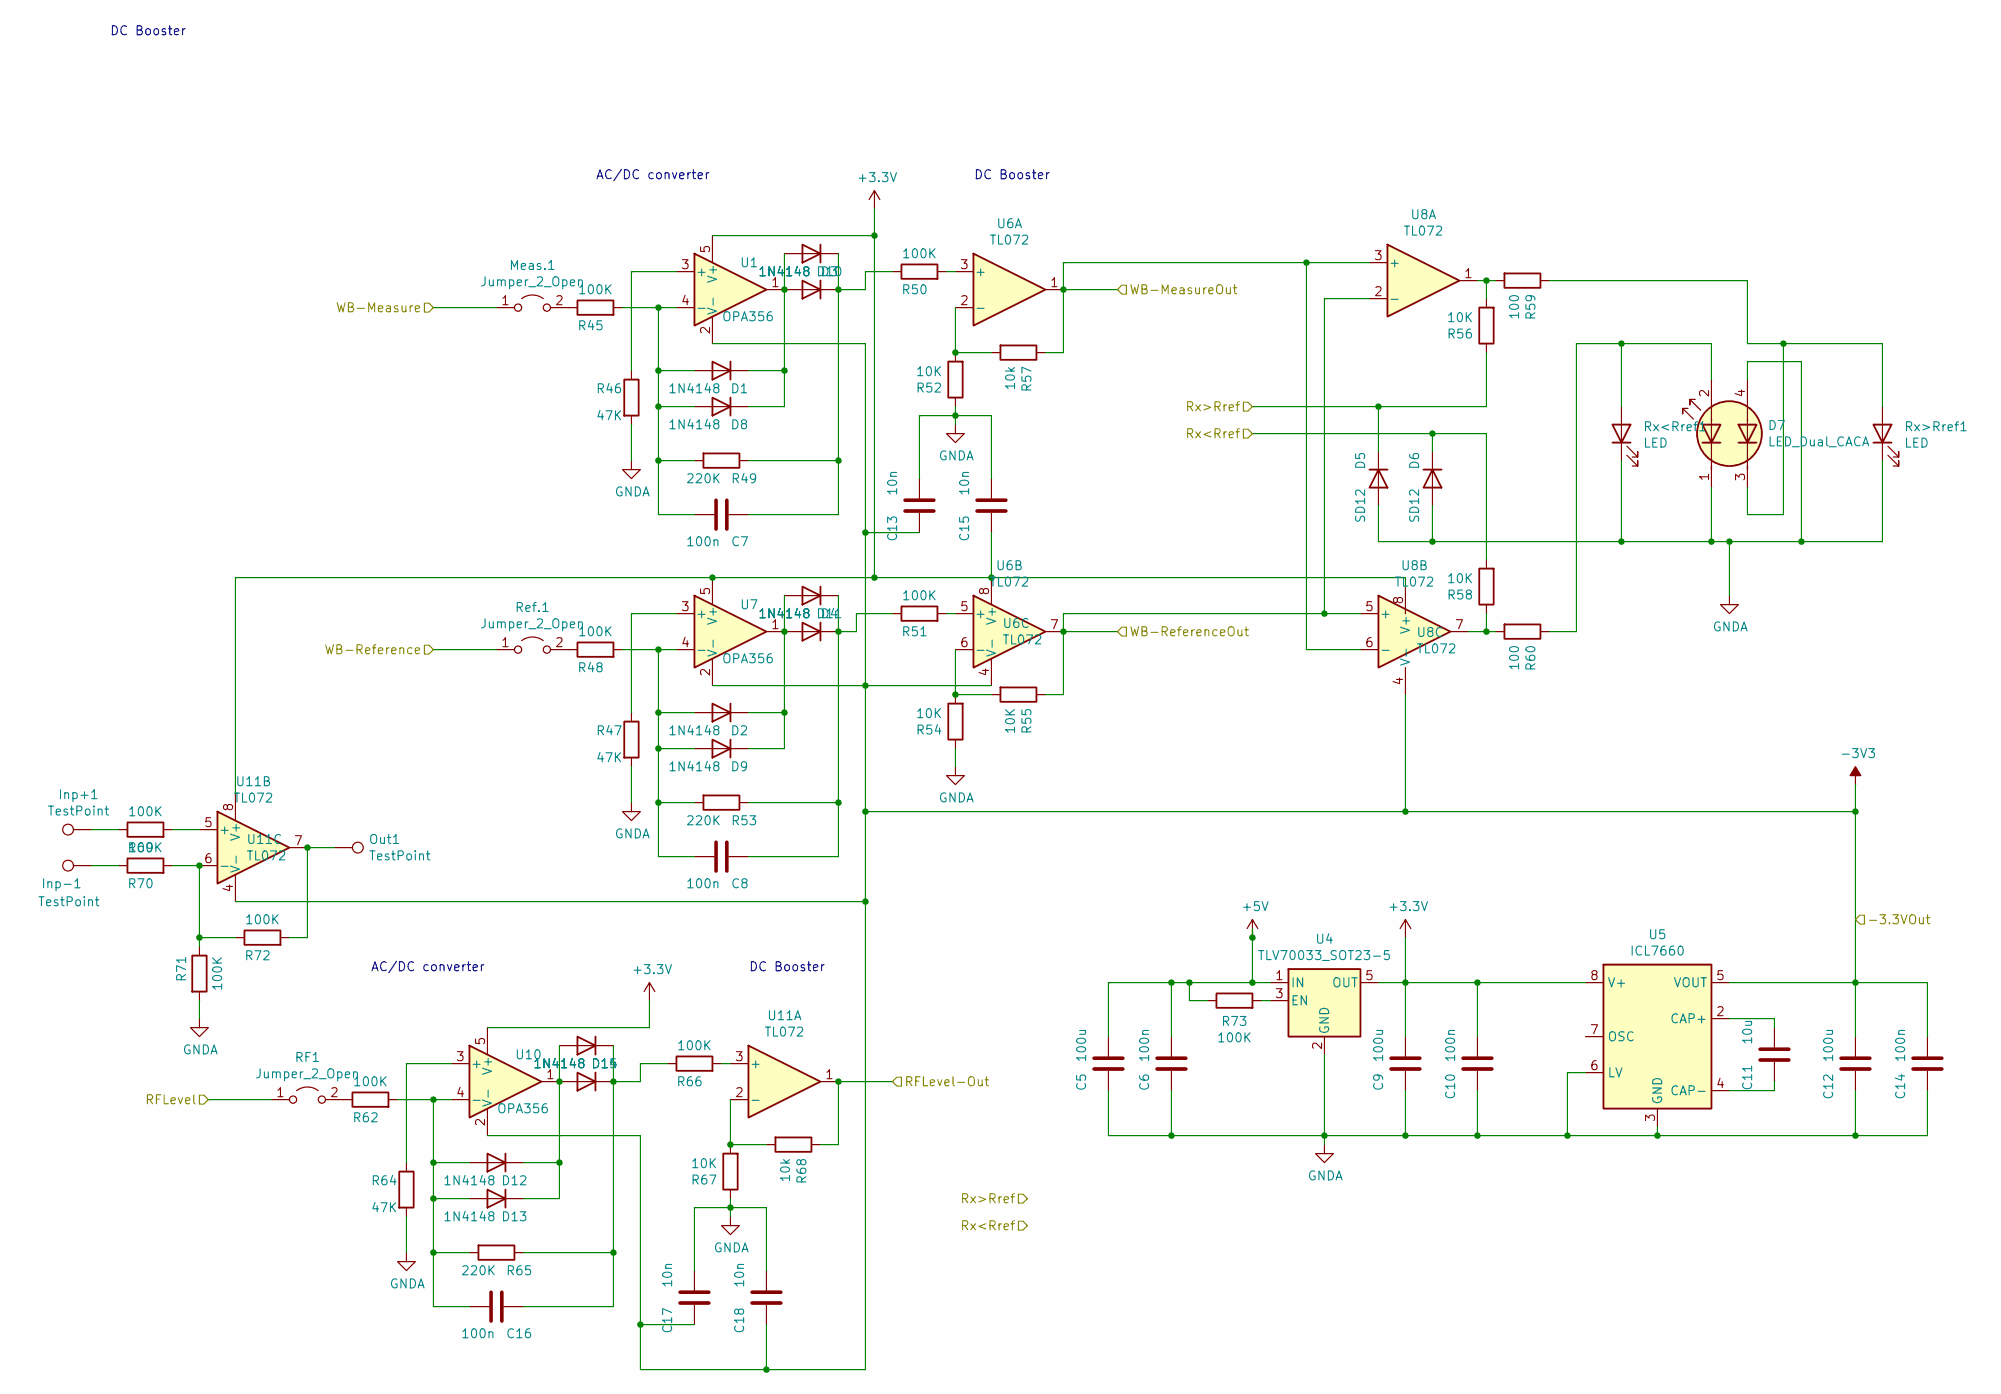
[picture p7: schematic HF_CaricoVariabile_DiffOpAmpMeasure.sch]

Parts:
C5, C9, C12: 100u; R_1210_3225Metric
C6, C7, C8, C10, C14, C16: 100n; R_1210_3225Metric
C11: 10u; R_1210_3225Metric
C13, C15, C17, C18: 10n; R_1210_3225Metric
D1, D2, D3, D4, D12, D15: 1N4148; D_DO-35_SOD27_P7.62mm_Horizontal
D5, D6: SD12; D_1812_4532Metric
D7: LED_Dual_CACA; LED_SK6812_EC15_1.5x1.5mm
D8, D9, D10, D11, D13, D14: 1N4148; D_1206_3216Metric
Inp+1: TestPoint; TestPoint_Pad_D1.5mm
Inp-1: TestPoint; TestPoint_Pad_D1.5mm
Meas.1: Jumper_2_Open; SolderJumper-2_P1.3mm_Open_RoundedPad1.0x1.5mm
Out1: TestPoint; TestPoint_Pad_D1.5mm
R45, R48, R50, R51, R62, R66, R69, R70, R71, R72, R73: 100K; R_1206_3216Metric_Pad1.30x1.75mm_HandSolder
R46, R47, R64: 47K; R_1206_3216Metric_Pad1.30x1.75mm_HandSolder
R49, R53, R65: 220K; R_1206_3216Metric_Pad1.30x1.75mm_HandSolder
R52, R54, R55, R56, R58, R67: 10K; R_1206_3216Metric_Pad1.30x1.75mm_HandSolder
R57, R68: 10k; R_1206_3216Metric_Pad1.30x1.75mm_HandSolder
R59, R60: 100; R_1206_3216Metric_Pad1.30x1.75mm_HandSolder
RF1: Jumper_2_Open; SolderJumper-2_P1.3mm_Open_RoundedPad1.0x1.5mm
Ref.1: Jumper_2_Open; SolderJumper-2_P1.3mm_Open_RoundedPad1.0x1.5mm
Rx<Rref1: LED; LED_1210_3225Metric
Rx>Rref1: LED; LED_1210_3225Metric
U1, U7, U10: OPA356; SOT-23-5
U4: TLV70033_SOT23-5; SOT-23-5
U5: ICL7660; SOIC-8_3.9x4.9mm_P1.27mm
U6, U8, U11: TL072; SOP-8_3.9x4.9mm_P1.27mm

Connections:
+3V3: C9.2, C10.2, C15.1, U1.5 (V+), U4.5 (OUT), U5.8 (V+), U6.8 (V+), U7.5 (V+), U8.8 (V+), U10.5 (V+), U11.8 (V+)
+5V: C5.2, C6.2, R73.1, U4.1 (IN); also elsewhere on the board
-3V3: C12.2, C13.1, C14.2, C17.1, C18.1, U1.2 (V-), U5.5 (VOUT), U6.4 (V-), U7.2 (V-), U8.4 (V-), U10.2 (V-), U11.4 (V-)
/HFCaricoVariabile-Load/HF Carico Variabile Differential OpAmp Measure/RFLevel: RF1.1 (A); also elsewhere on the board
/HFCaricoVariabile-Load/HF Carico Variabile Differential OpAmp Measure/WB-Measu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: Meas.1.1 (A); also elsewhere on the board
/HFCaricoVariabile-Load/HF Carico Variabile Differential OpAmp Measure/WB-Refer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: Ref.1.1 (A); also elsewhere on the board
/HFCaricoVariabile-Load/RFLevel-Out: R68.1, U11.1; also elsewhere on the board
/HFCaricoVariabile-Load/Rx<Rref: D6.1 (K), R58.2; also elsewhere on the board
/HFCaricoVariabile-Load/Rx>Rref: D5.1 (K), R56.1; also elsewhere on the board
/HFCaricoVariabile-Load/WB-MeasureOut: R57.1, U6.1, U8.3 (+), U8.6 (-); also elsewhere on the board
/HFCaricoVariabile-Load/WB-ReferenceOut: R55.1, U6.7, U8.2 (-), U8.5 (+); also elsewhere on the board
GNDA: C5.1, C6.1, C9.1, C10.1, C12.1, C13.2, C14.1, C15.2, C17.2, C18.2, D5.2 (A), D6.2 (A), D7.1 (A1), D7.4 (K2), R46.2, R47.2, R52.1, R54.1, R64.2, R67.1, R71.2, Rx<Rref1.1 (K), Rx>Rref1.1 (K), U4.2 (GND), U5.3 (GND), U5.6 (LV); also elsewhere on the board
unnamed: C7.1, D3.1 (K), D10.1 (K), R49.1, R50.1
unnamed: C7.2, D1.2 (A), D8.2 (A), R45.2, R49.2, U1.4 (-)
unnamed: C8.1, D4.1 (K), D11.1 (K), R51.1, R53.1
unnamed: C8.2, D2.2 (A), D9.2 (A), R48.2, R53.2, U7.4 (-)
unnamed: C11.1, U5.4 (CAP-)
unnamed: C11.2, U5.2 (CAP+)
unnamed: C16.1, D14.1 (K), D15.1 (K), R65.1, R66.1
unnamed: C16.2, D12.2 (A), D13.2 (A), R62.2, R65.2, U10.4 (-)
unnamed: D1.1 (K), D3.2 (A), D8.1 (K), D10.2 (A), U1.1
unnamed: D7.2 (K1), R60.1, Rx<Rref1.2 (A)
unnamed: D7.3 (A2), R59.1, Rx>Rref1.2 (A)
unnamed: D2.1 (K), D4.2 (A), D9.1 (K), D11.2 (A), U7.1
unnamed: D12.1 (K), D13.1 (K), D14.2 (A), D15.2 (A), U10.1
unnamed: Inp+1.1, R69.1
unnamed: Inp-1.1, R70.1
unnamed: Meas.1.2 (B), R45.1
unnamed: Out1.1, R72.2, U11.7
unnamed: R46.1, U1.3 (+)
unnamed: R47.1, U7.3 (+)
unnamed: R48.1, Ref.1.2 (B)
unnamed: R50.2, U6.3 (+)
unnamed: R51.2, U6.5 (+)
unnamed: R52.2, R57.2, U6.2 (-)
unnamed: R54.2, R55.2, U6.6 (-)
unnamed: R56.2, R59.2, U8.1
unnamed: R58.1, R60.2, U8.7
unnamed: R62.1, RF1.2 (B)
unnamed: R64.1, U10.3 (+)
unnamed: R66.2, U11.3 (+)
unnamed: R67.2, R68.2, U11.2 (-)
unnamed: R69.2, U11.5 (+)
unnamed: R70.2, R71.1, R72.1, U11.6 (-)
unnamed: R73.2, U4.3 (EN)

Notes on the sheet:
AC/DC converter
DC Booster

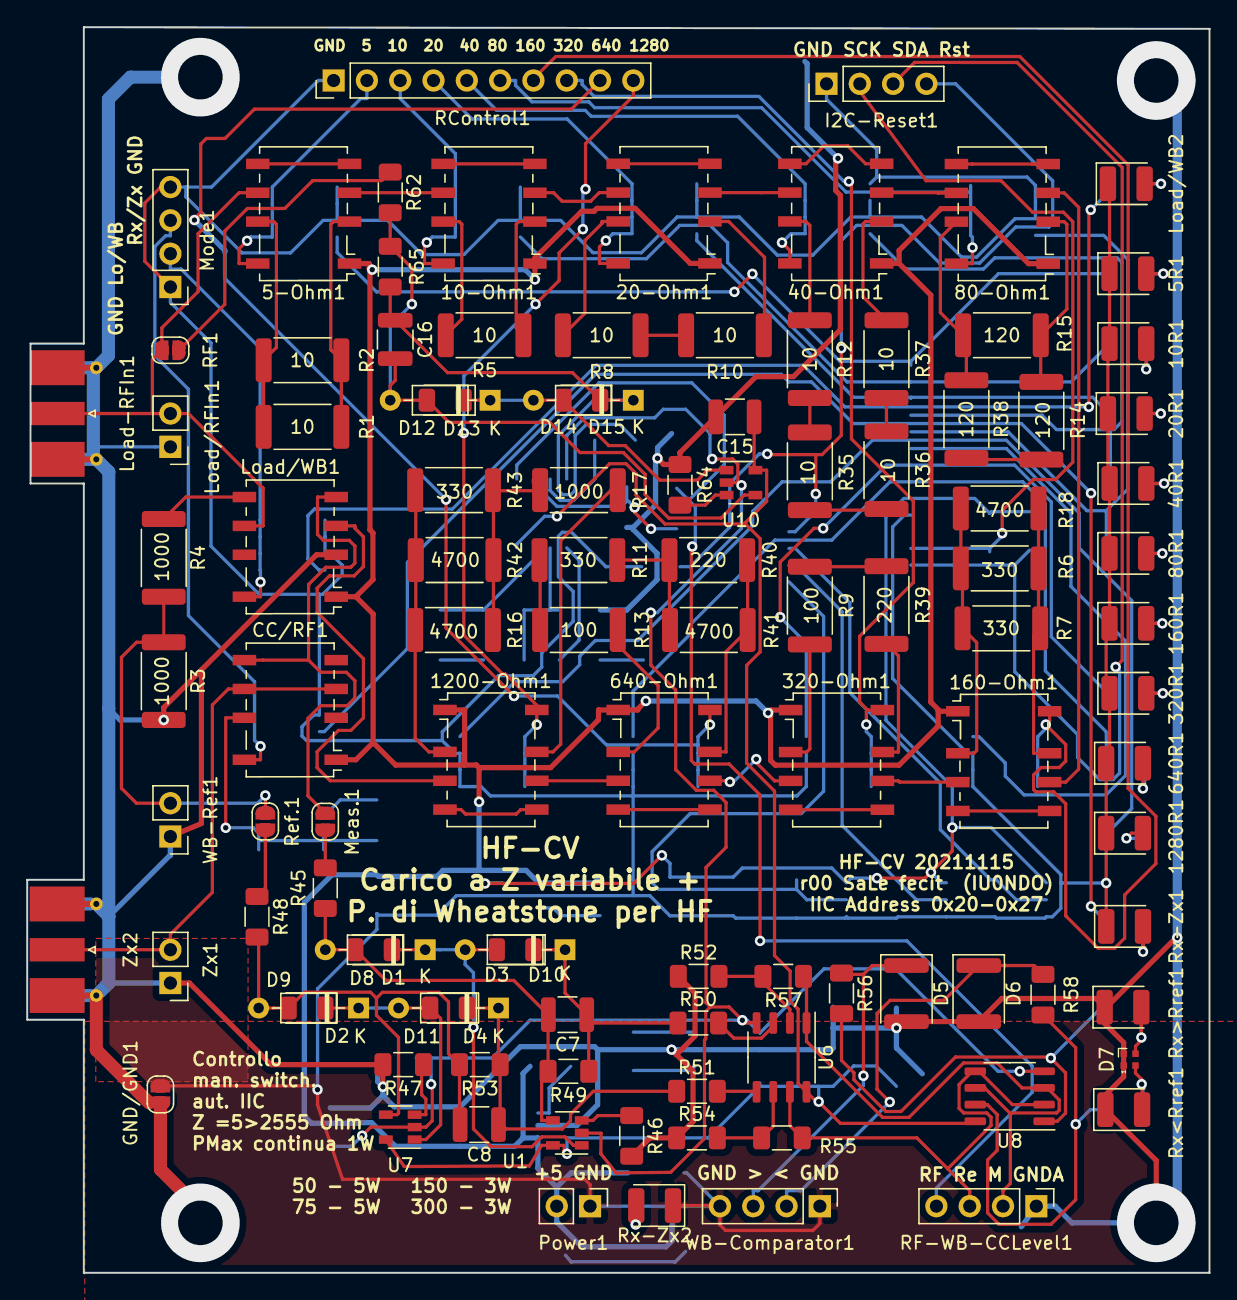
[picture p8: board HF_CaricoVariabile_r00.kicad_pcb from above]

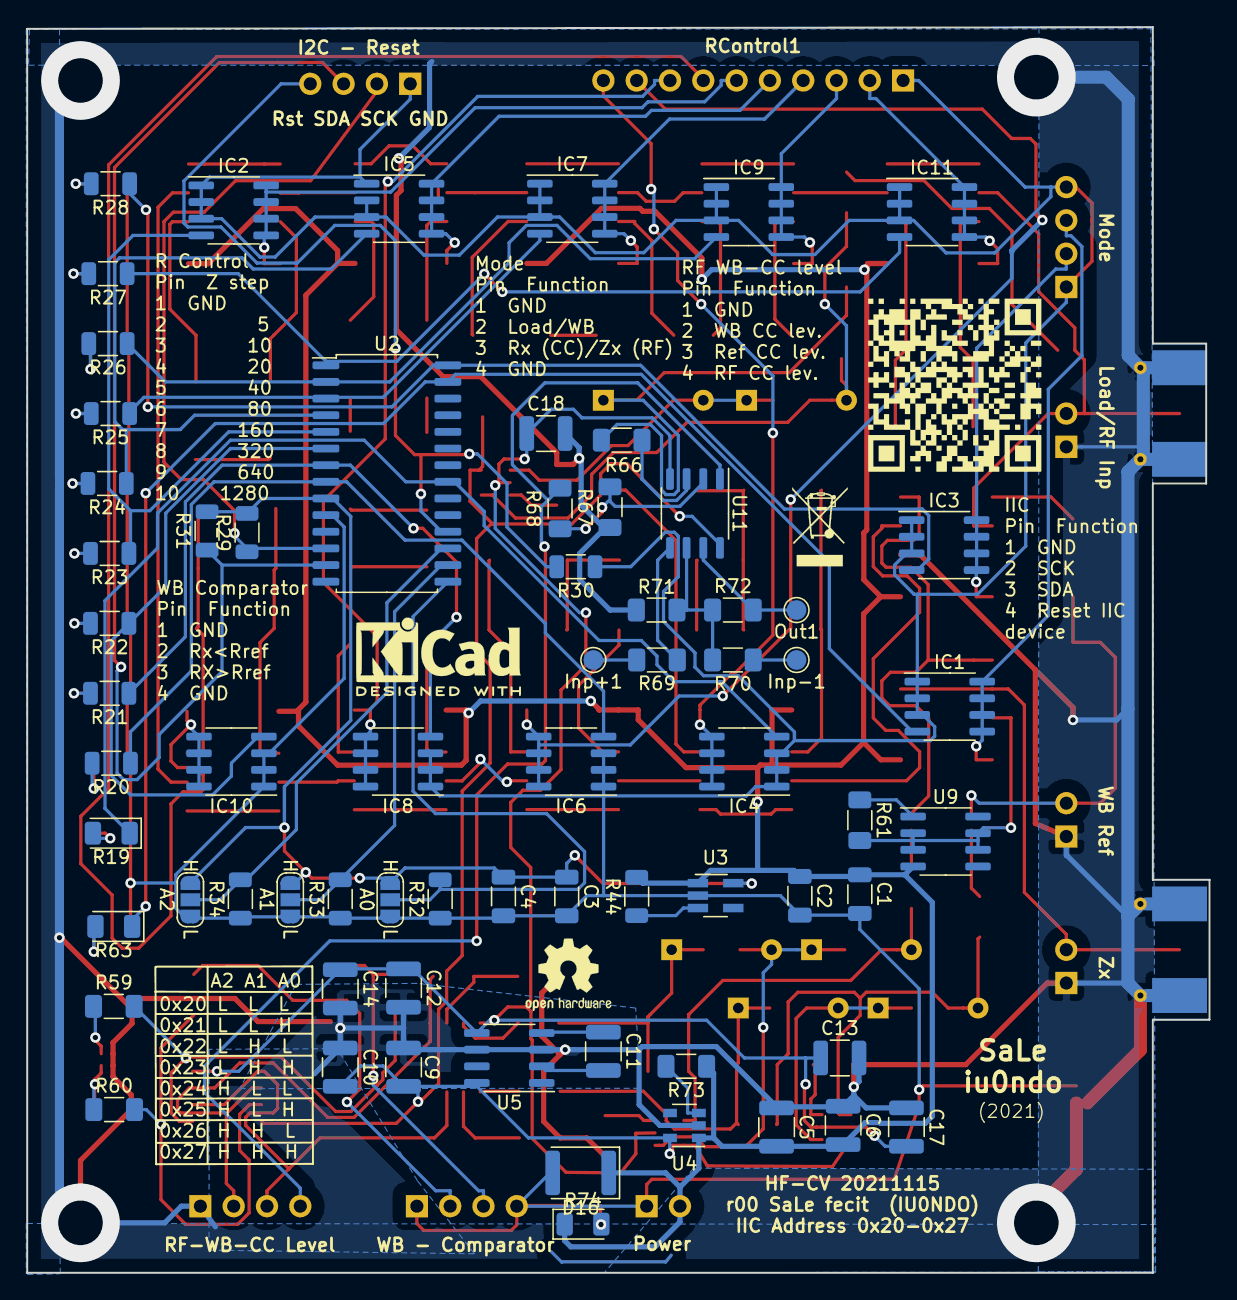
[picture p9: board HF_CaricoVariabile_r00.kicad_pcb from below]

Board: 2 copper layers, 90.2 x 95.0 mm, 177 parts (69 on the bottom side), 137 nets.

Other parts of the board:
QR*****: HF_CaricoVaribile_QR-Code-Piccolo-r00
